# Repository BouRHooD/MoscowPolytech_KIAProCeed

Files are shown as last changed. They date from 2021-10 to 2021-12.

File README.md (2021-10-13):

<h1 align="center">Self-driving KIA ProCeed</h1>

---

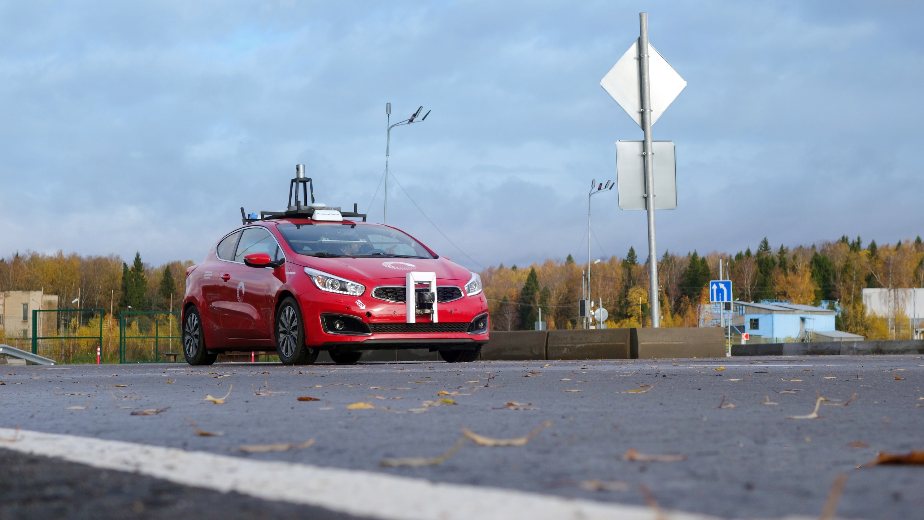
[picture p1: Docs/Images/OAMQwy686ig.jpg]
Иллюстрация к проекту


<p align="center">


  

  

  
</p>

RU: Беспилотное транспортное средство (БПТС) KIA ProCeed. Разрабатывается с использование микроконтроллеров Arduino, GNSS приёмник, Velodyne 3-D Lidar. Воздействие на органы управления автомобиля происходит посредством механических и электронных влияний, которые имитируют действия человека. Воздействие на руль происходит посредством DC мотора и потенциометра, который считывает текущее положение руля. Воздействие на педали сцепления и тормоза с помощью сервомоторов. Воздействие на педаль газа происходит с помощью ЦАП. 

Оборудование KIA ProCeed:
* **Лидар**, который нужен для определения положения автомобиля в пространстве и распознавания типов препятствий.
* **Приемник RTK GNSS**, обеспечивающий сантиметровую точность позиционирования автомобиля по спутникам GPS+ГЛОНАСС и поправкам наземных станций.

---

<h1 align="left"> Документация </h1>

[Инcтрукция по запуску автомобиля](https://github.com/BouRHooD/MoscowPolytech_KIAProCeed/raw/main/Docs/Connect_/Manual_po_ispolzovaniyu_KIA_ProCeed.pdf)

<h1 align="left"> Контакты </h1>
С нами можно связаться по почте bourhood@gmail.com

А еще у нас есть [Instagram](https://www.instagram.com/self.driving.mpu/?r=nametag)

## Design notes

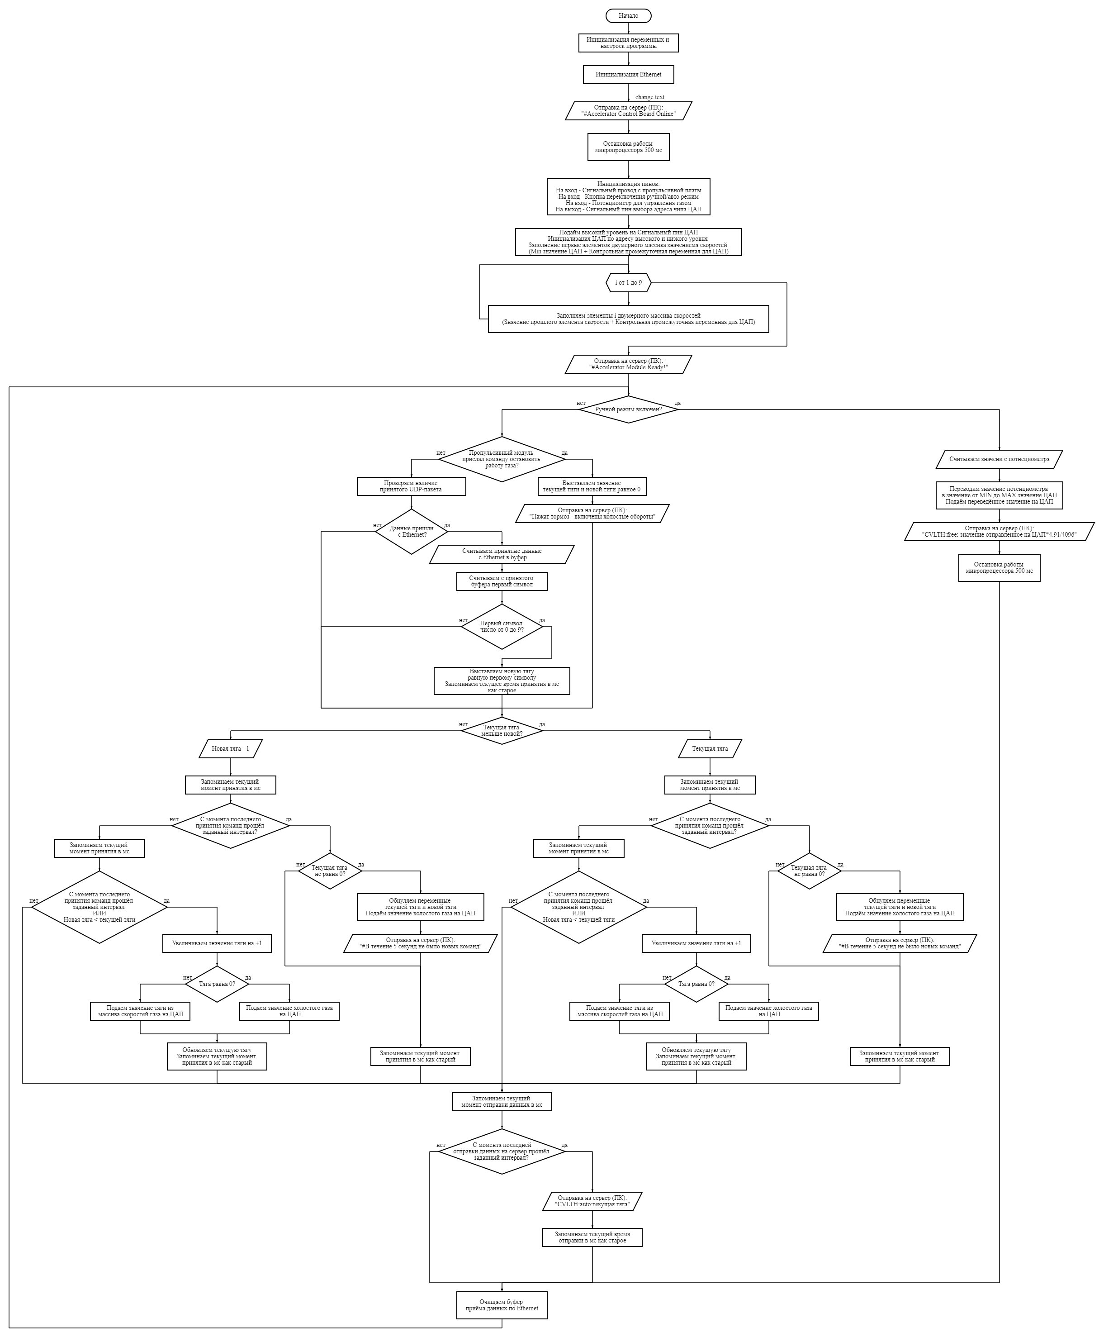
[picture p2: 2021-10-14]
Docs/Schemes/визуализация алгоритма управления газом Pro Ceed.png

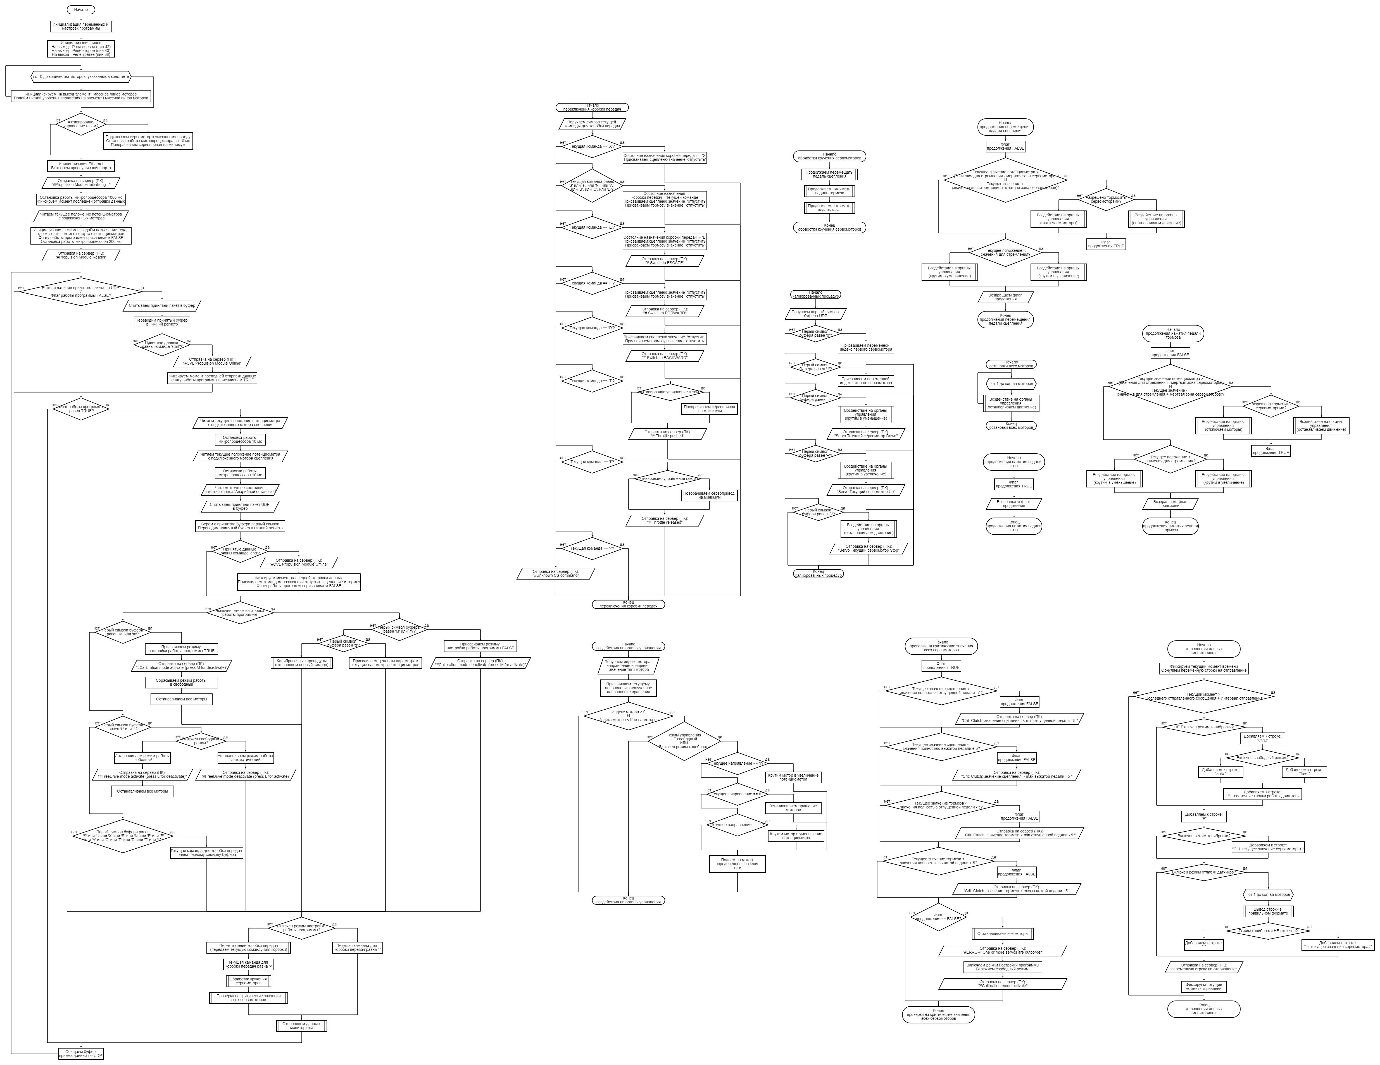
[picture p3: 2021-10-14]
Docs/Schemes/визуализация алгоритма пропульсивного модуля Pro Ceed.png

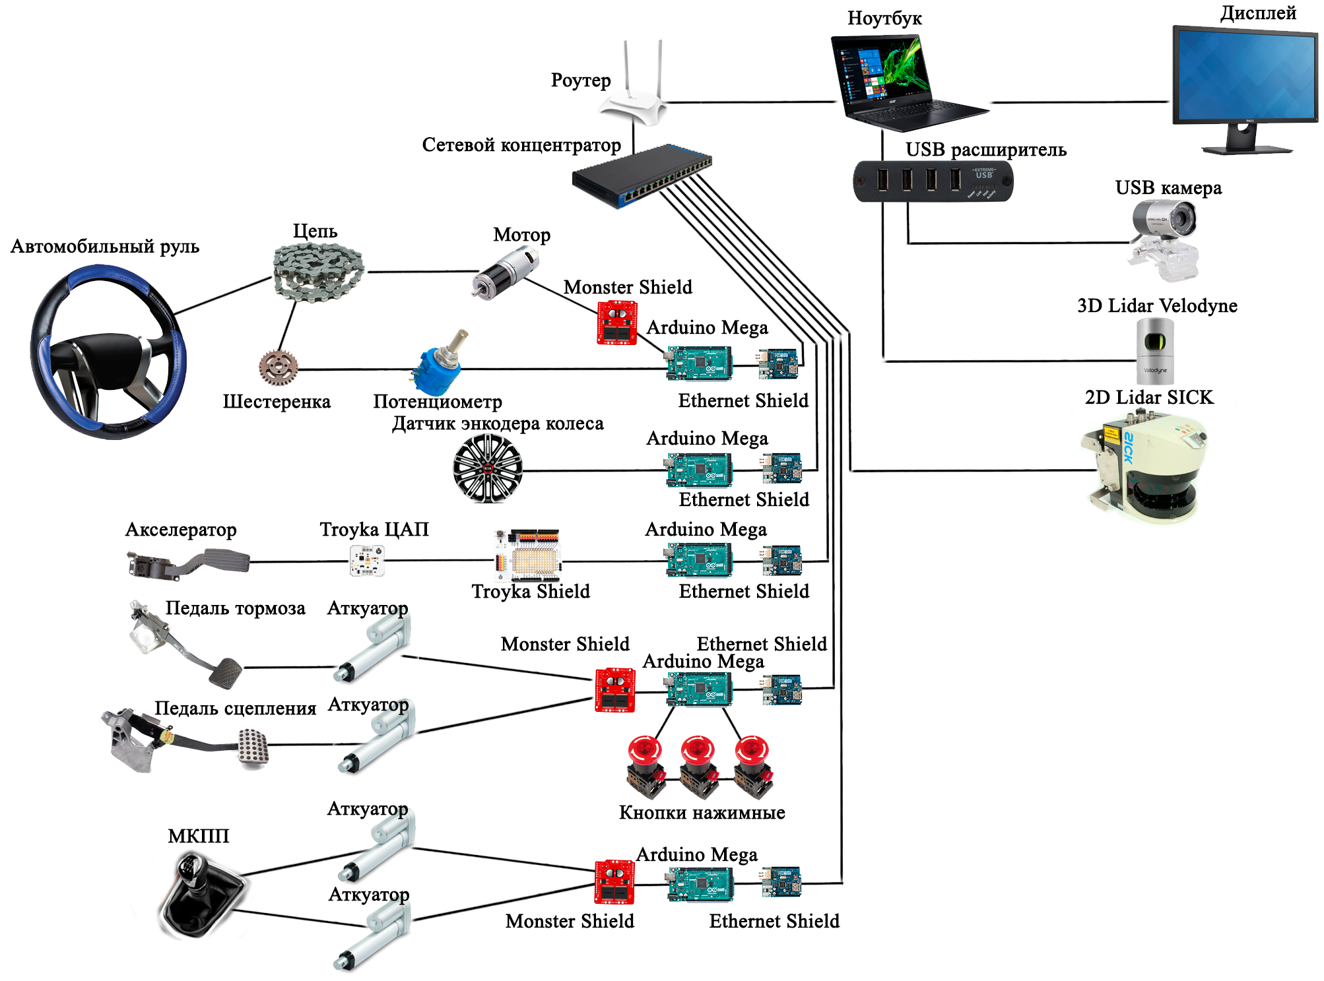
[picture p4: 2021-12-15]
Docs/Connect_/TopologyProject/Для топологии проекта KIA ProCeed.png

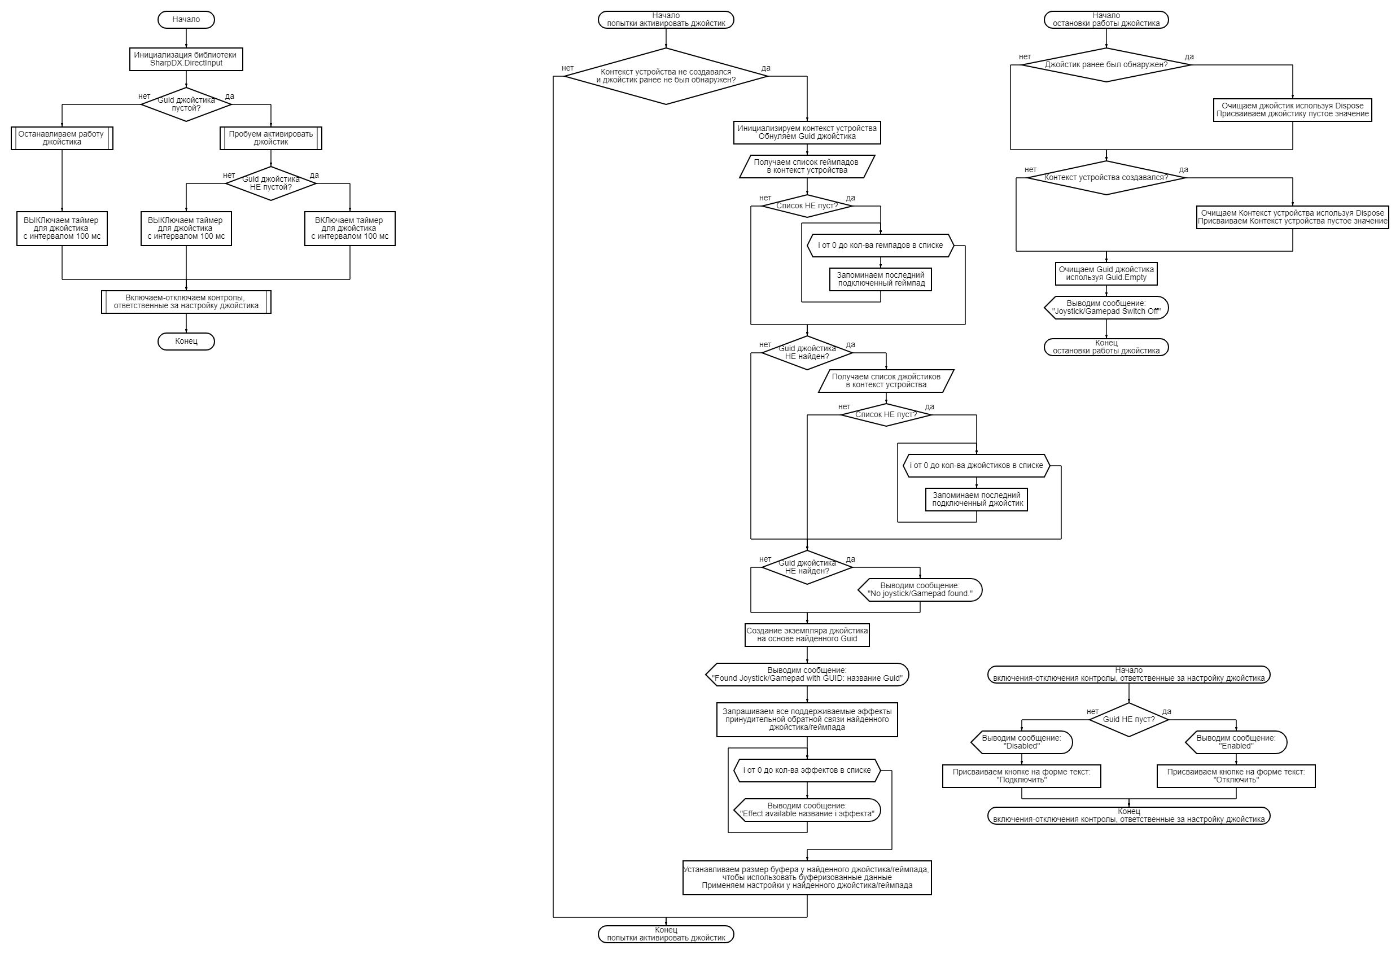
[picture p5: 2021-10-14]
Docs/Schemes/визуализация алгоритма управления джойстиком машины.png

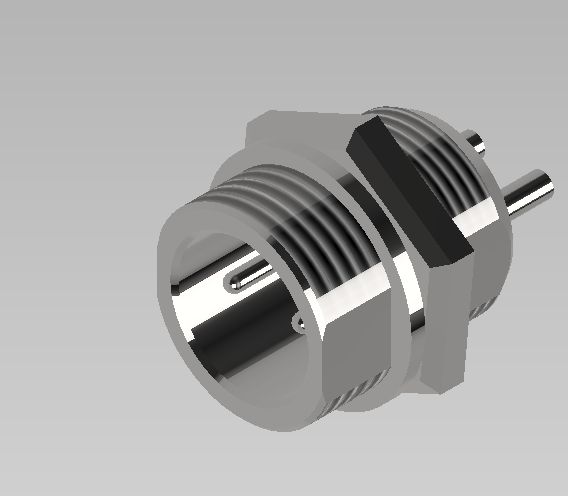
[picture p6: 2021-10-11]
Modeling/Blanks_Model/Руль (модуль)/3-pin/pic.jpg

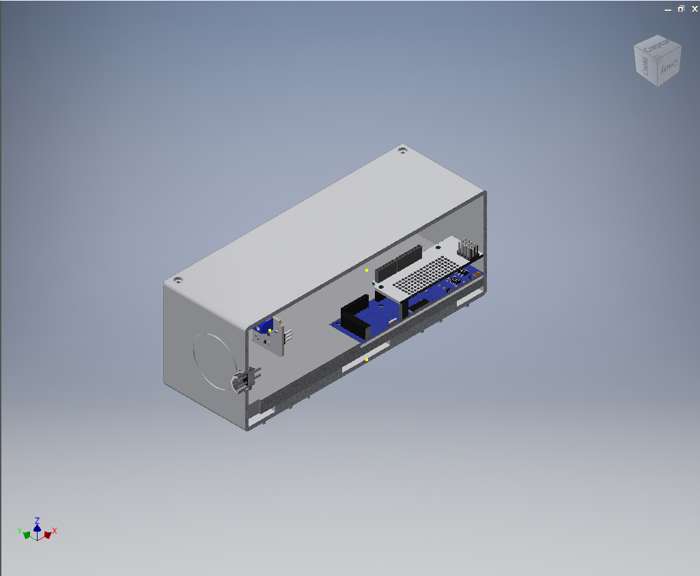
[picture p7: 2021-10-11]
Modeling/Blanks_Model/Газ (модуль)/Screenshot_4.png

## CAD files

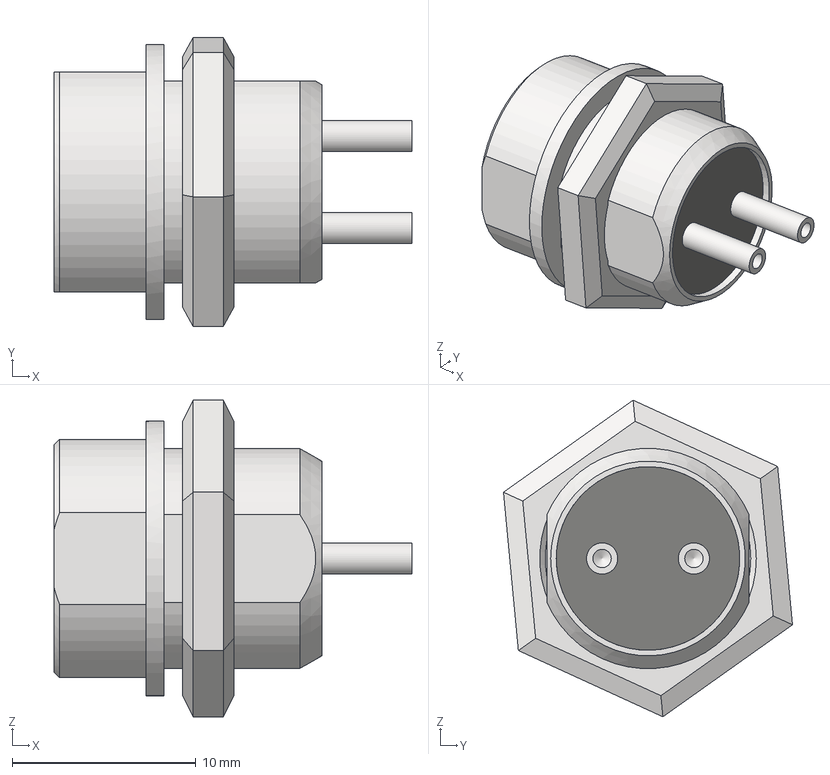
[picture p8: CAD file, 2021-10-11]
Modeling/Blanks_Model/Газ (модуль)/3-pin/3-pin.stp
19.5 x 15.7 x 17.2 mm
корпус разъема
каркас
kls_pin x 2
гайка

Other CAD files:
Modeling/Blanks_Model/New Дистанционная связь (модуль)/Arduino UNO.ipt
Modeling/Blanks_Model/New Дистанционная связь (модуль)/Arduino UNO/Arduino_Uno.ipt
Modeling/Blanks_Model/New Дистанционная связь (модуль)/NextionDisplay.ipt
Modeling/Blanks_Model/New Дистанционная связь (модуль)/OldVersions/A_Arduino_Uno_Wifi_Shield.0005.iam
Modeling/Blanks_Model/New Дистанционная связь (модуль)/OldVersions/Arduino_Wifi_Shield.0010.ipt
Modeling/Blanks_Model/New Дистанционная связь (модуль)/OldVersions/Monster_motor_Shield.0019.ipt
Modeling/Blanks_Model/New Дистанционная связь (модуль)/OldVersions/NextionDisplay.0002.ipt
Modeling/Blanks_Model/New Дистанционная связь (модуль)/OldVersions/Relay.0013.ipt
Modeling/Blanks_Model/New Дистанционная связь (модуль)/OldVersions/Аккумулятор.0001.ipt
Modeling/Blanks_Model/New Дистанционная связь (модуль)/OldVersions/Джойстик.0003.ipt
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

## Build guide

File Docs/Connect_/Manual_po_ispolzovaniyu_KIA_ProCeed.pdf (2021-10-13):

## Мануал по использованию KIA ProCeed

## Версия продукта 0.3

## Содержание

### 1. Проверка исправности ProCeedперед и после эксплуатации - Проверить целостность проводки

## Визуально оценить все ли в порядке – провода надежно подключены ко

всем элементам в обоих багажниках (первый в задней части машины, второй на крыше машины).

### - Проверить заряд аккумуляторов (под капотом и в багажнике)

## Если аккумуляторы подключены к машине, то включаем прерыватель масс, а затем смотрим на вольметры на основной панели и на месте держателя очков (?)

## Если аккумуляторы не подключены к машине, то можем проверить их заряд с помощью мультиметра

### - Убедиться, что все элементы надежно закреплены на машине

## Проверить крепления в обоих багажниках, элементы должны быть неподвижны. Также убедиться, что багажник прикручен саморезами к машине

### - Проверить уровень топлива

## Посмотреть на приборной панели уровень топлива

### - Проверить работоспособность всех Kill-Switch’ей

## Завести двигатель машины, а затем нажать на Kill-Switch, если машина заглохла, то кнопка работает (проделать операцию с каждой такой кнопкой)

## В случае обнаружения проблемобратиться к старшему по команде

### 2. Инструкция по эксплуатации ProCeed

### 1. Включение

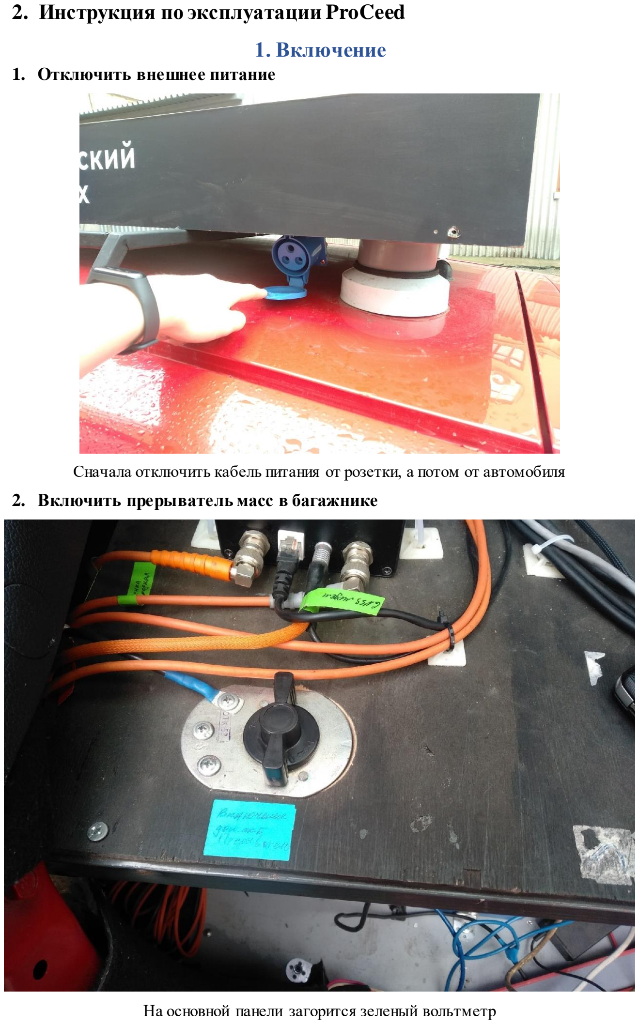
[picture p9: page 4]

### 1. Отключить внешнее питание

Сначала отключить кабель питания от розетки, а потом от автомобиля

### 2. Включить прерыватель масс в багажнике

На основной панели загорится зеленый вольтметр

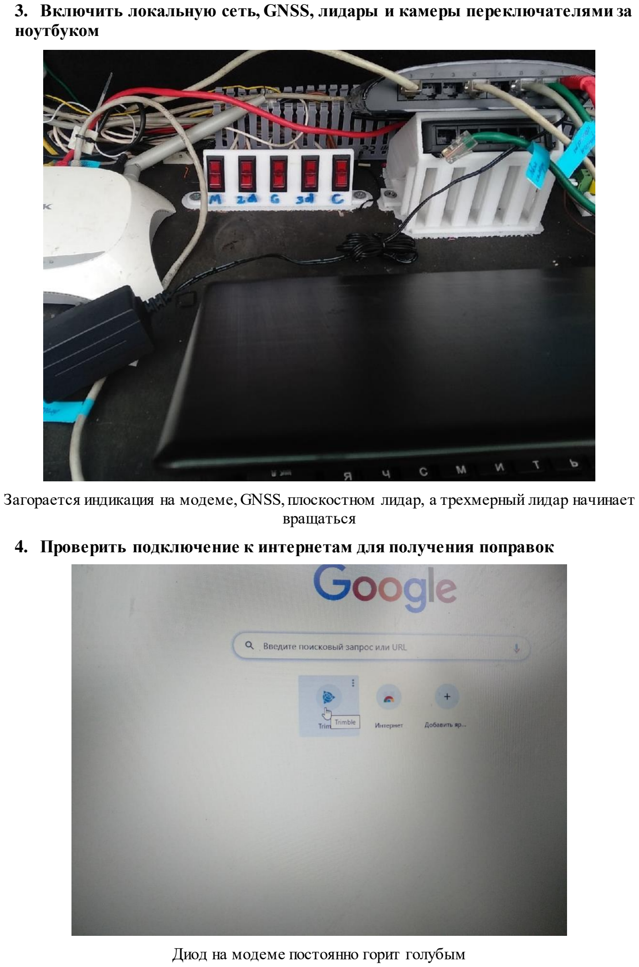
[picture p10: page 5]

### 3. Включить локальную сеть, GNSS, лидары и камеры переключателями за

ноутбуком

Загорается индикация на модеме, GNSS, плоскостном лидар, а трехмерный лидар начинает вращаться

### 4. Проверить подключение к интернетам для получения поправок

Диод на модеме постоянно горит голубым

### 5. На рабочем столе запустить файл Robocross2018

### 6. В окне “Подключение оборудования” подключить платы управления в

соответствии с портами подключения

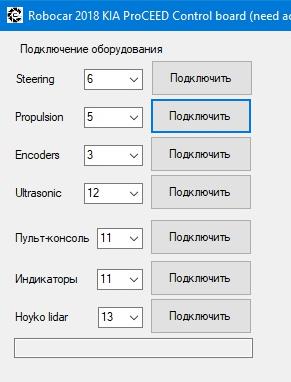
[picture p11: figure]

Steering 6, Propulsion 5, Encoders 3, Пульт консоль 11, Индикаторы 11 и т.д. В соответвующих окнах появятся данные от датчиков обратной связи

### 7. В окне настроек RTK подключить систему GNSS

В соответвующих окнах появятся координаты и курс из протокола NMEA. При отсутствии курса, окно курса имеет красный цвет. Состояние приемника проверяется по адресу 192.168.0.3

### 8. В окне “Запуск миссии”, выбрать нужную миссию. Нажать на кнопку

“Загрузить миссию”

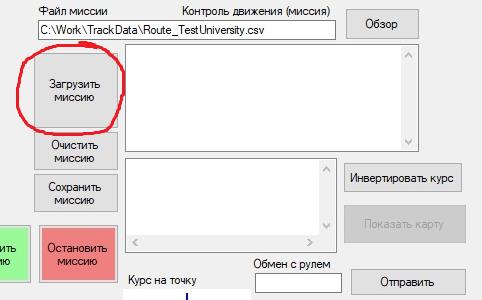
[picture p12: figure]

В консоли появятся координаты и курс. Если система GNSS работает корректно, то на карте появятся точки

### 9. Запустить двигатель

Прожать педаль сцепления и одновременно повернуть вставленный ключ зажигания по часовой стрелке

### 10. Включить основное питание на передней панели

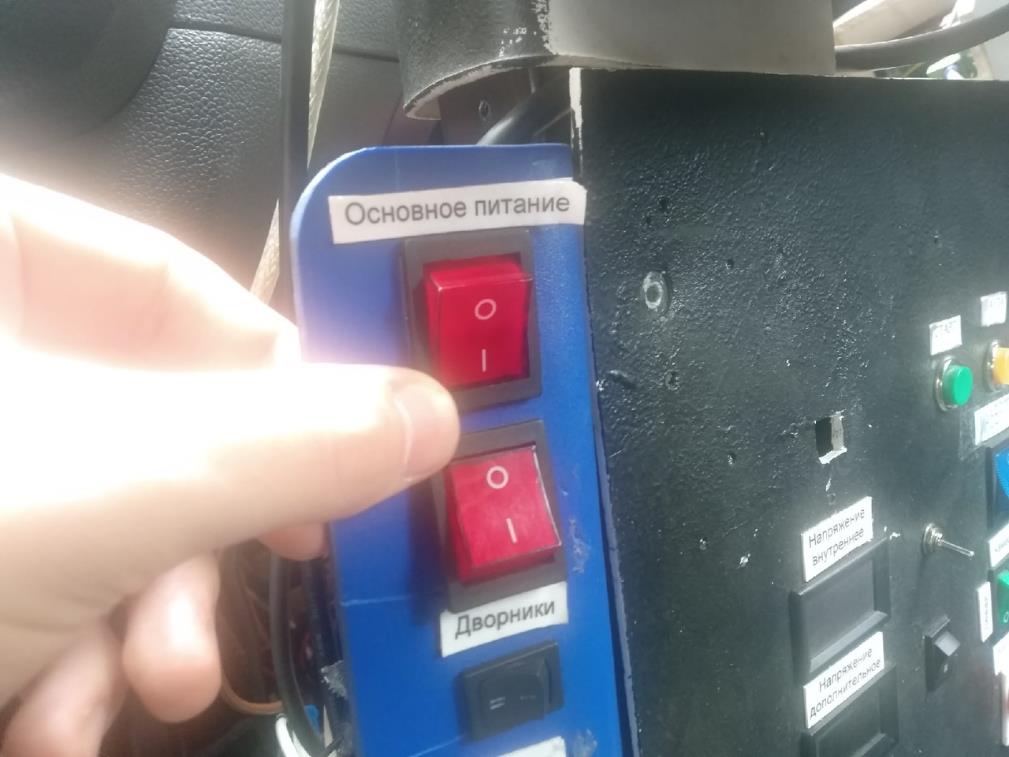
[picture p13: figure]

Загорится красный вольтметр, а на платах загорятся красные диоды

### 11. Перевести пропульсивный модуль в свободный режим, отправив команду

M

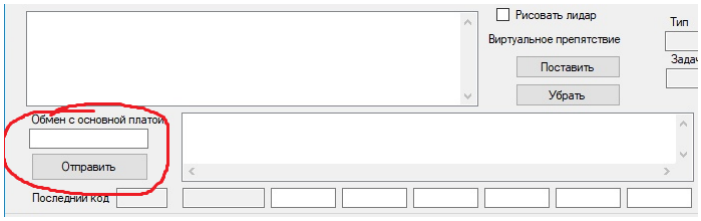
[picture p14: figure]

### 12. Перевести пропульсивный модуль в автоматический режим, отправив

команду L

### 13. В консоль пропульсивного модуля отправить букву E

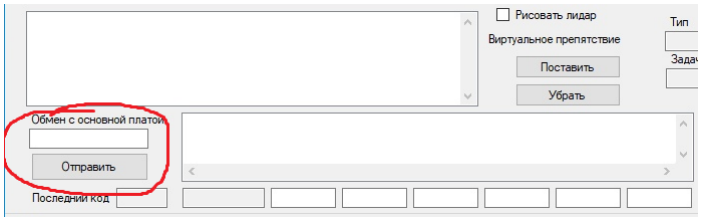
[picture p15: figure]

Актуаторы задвинутся в начальное положение

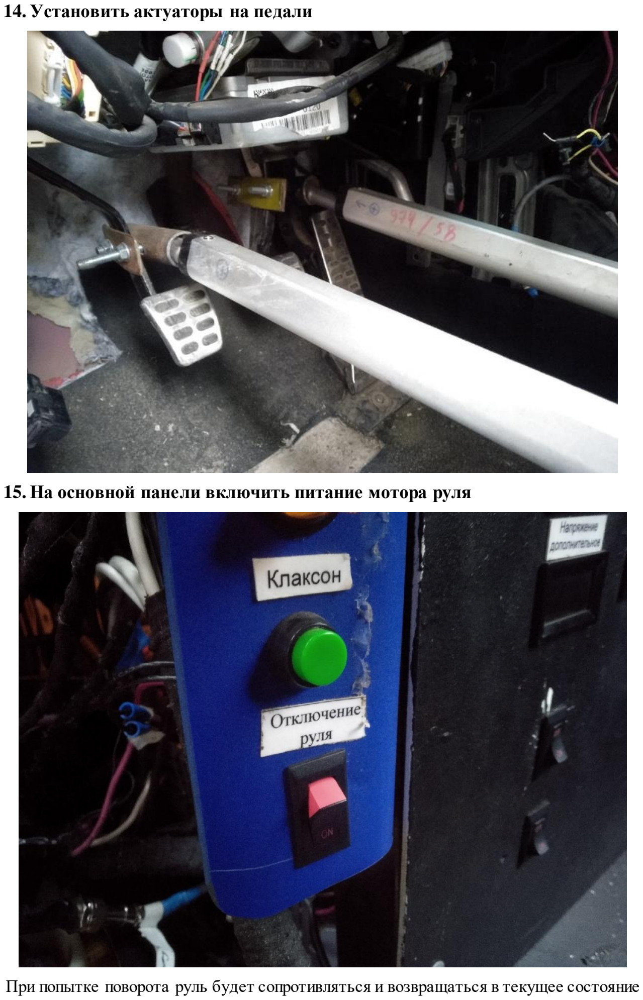
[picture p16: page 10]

### 14. Установить актуаторы на педали

### 15. На основной панели включить питание мотора руля

При попытке поворота руль будет сопротивляться и возвращаться в текущее состояние

### 16. Перевести модуль управления руля в автоматический режим, отправив

команду A

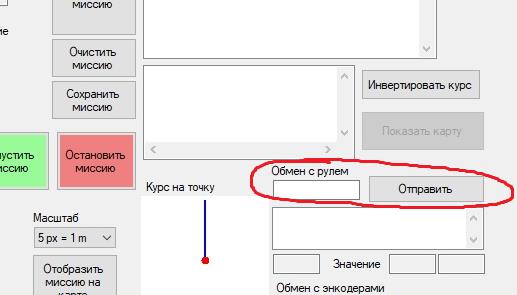
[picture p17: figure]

### 17. Отправить в консоль пропульсивного модуля команду B

Актуаторы тормоза и сцепления нажмут на педали

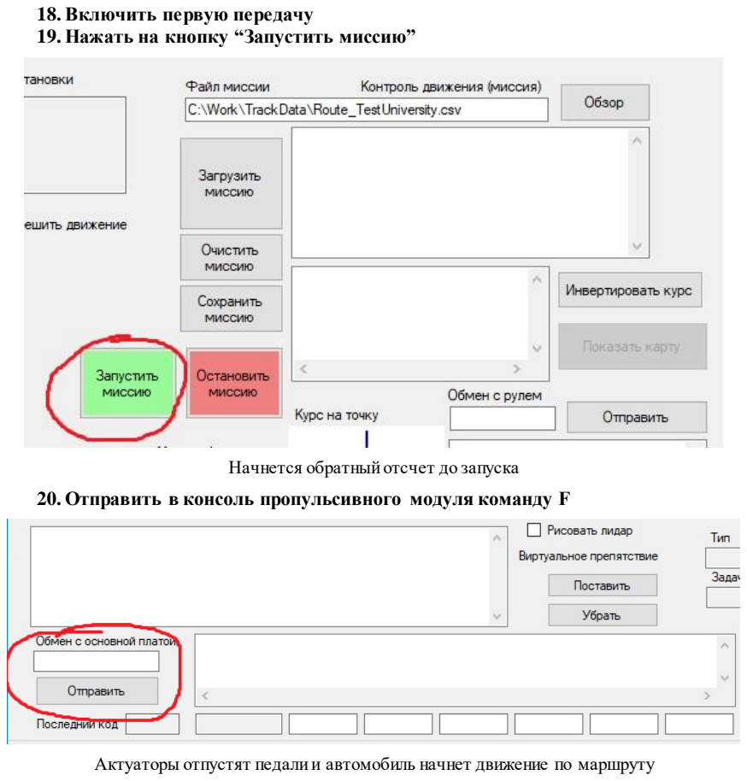
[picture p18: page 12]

### 18. Включить первую передачу 19. Нажать на кнопку “Запустить миссию”

Начнется обратный отсчет до запуска

### 20. Отправить в консоль пропульсивного модуля команду F

Актуаторы отпустят педали и автомобиль начнет движение по маршруту

### 2.Выключение

### 1. Заглушить двигатель

В положении покоя машины повернуть ключ против часовой стрелки

### 2. Поставить автомобиль на ручник 3. В консоль пропульсивного модуля отправить команду E

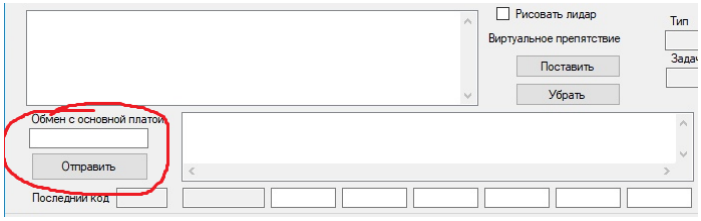
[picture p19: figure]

Актуаторы задвинутся в начальное положение

### 4. Снять актуаторы с педалей 5. На основной панели выключить питание мотора руля

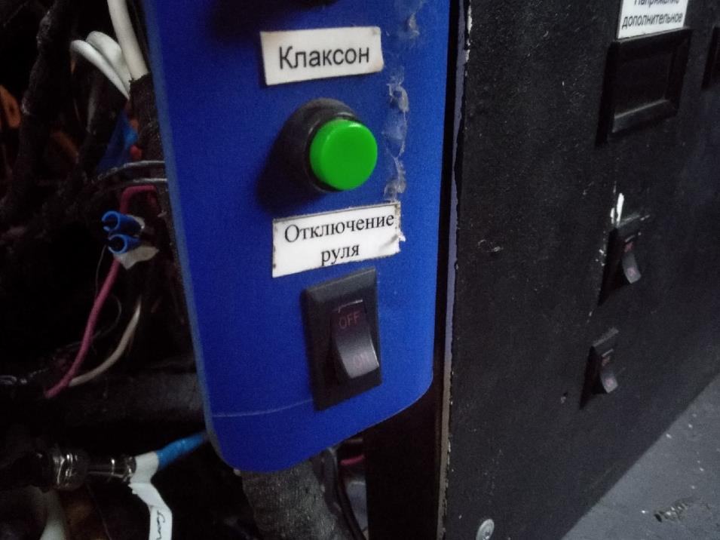
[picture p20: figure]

При попытке поворота руль не будет сопротивляться и возвращаться в текущее состояние

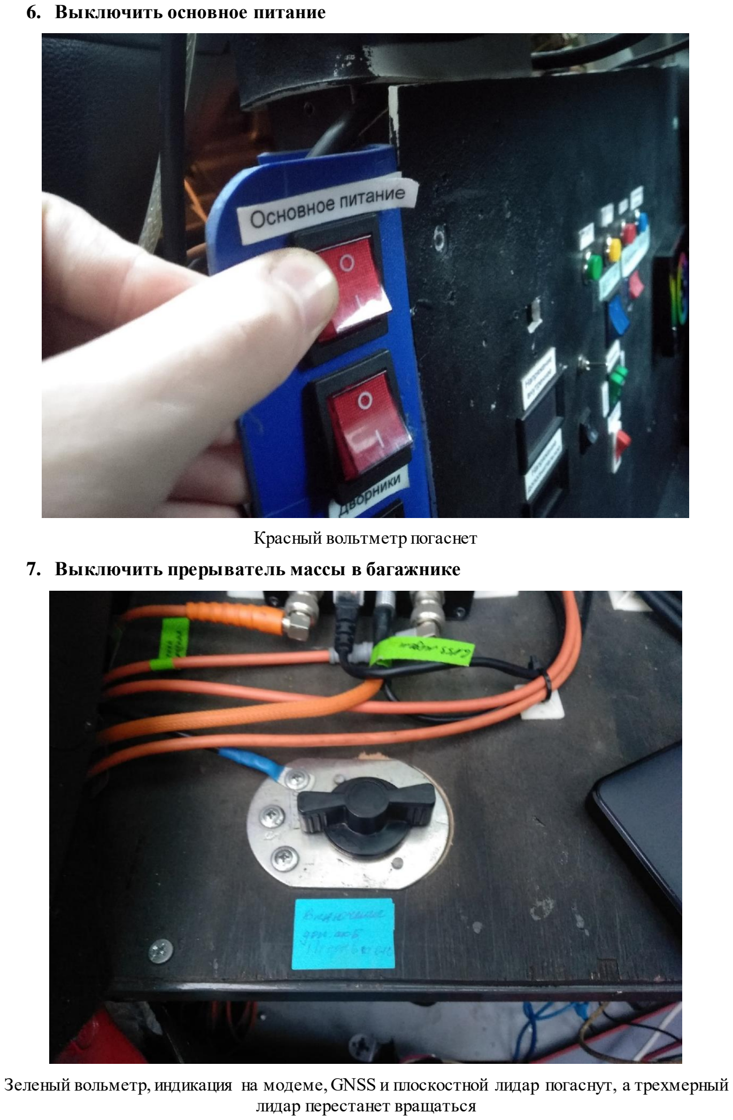
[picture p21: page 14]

### 6. Выключить основное питание

Красный вольтметр погаснет

### 7. Выключить прерыватель массы в багажнике

Зеленый вольметр, индикация на модеме, GNSS и плоскостной лидар погаснут, а трехмерный лидар перестанет вращаться

### 8. Подключить внешнее питание для зарядки

Сначала подключение к машине, а потом к розетке

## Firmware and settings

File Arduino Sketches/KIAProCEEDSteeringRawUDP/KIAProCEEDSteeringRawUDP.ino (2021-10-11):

/*
Система управления платой контроля рулевого колеса Робокара Мосполитеха (в конфигурации "Зимний город 2019") для KIA ProCeed

Версия 23.10.2020 by Leonov Vladislav 181-311

Введена коррекция скорости вращения (снижение мощности при приближении к зоне точного руления)

Система управления с 1 x Arduino Uno, 1 x Monster Shield, 1 x Troyka Shield, 1 х Тумблер, 1 x Ethernet Shield

"Механическая" калибровка: *  
  - мотор руля: при прямом включении должен крутиться вправо
  - потенциометр руля:
     - возрастает при вращении руля вправо
     - 500 в средней позиции (прямо)

!!!!!  ВАЖНО  !!!!
Ведется непрерывный контроль тока через рулевой мотор. В случае превышения номинального значения 
мотор отключается с индикацией авария в 1 (авария)
!!!!!  ВАЖНО  !!!!

К плате подключен тумблер отключения автоматического режима руления.

При включении платы даже в автоматическом режиме (тумблер) вращение не производится до поступления по Serial
любой корректной команды активации вращения (число от 100 до 999).

Конфигурация системы:
Arduino Uno
Monster Motor Shield
Troyka Shield
Ethernet Shield

Управляющие и мониторинговые пины:
Руль (Steering)

Управление через Ethernet Shield (штатный режим):

{100 - 999}  руль   100 - влево до упора, 500 - середина, 999 - вправо до упора
Окончание ввода # или \n. Можно подождать 0,5 секунды и строка обработается сама.

S         остановка вращения руля
F         свободный режим
A         включение автоматического режима (после F)

Тумблер не связан с командами программного управления, а отключает "передачу команд на мотор".
*/

// Настройки внешних устройств 
#define ledPin 13                                           // Мигаем светодиодом при исправной работе
 
//  ------------------------------ РУЛЬ ------------------------------
/*
int inApin[2] = {7, 4};  // INA: Clockwise input
int inBpin[2] = {8, 9}; // INB: Counter-clockwise input
int pwmpin[2] = {5, 6}; // PWM input
int cspin[2] = {2, 3}; // CS: Current sense ANALOG input
int enpin[2] = {0, 1}; // EN: Status of switches output (Analog pin)
 */
#define SteeringPinA    4
#define SteeringPinB    9
#define SteeringPWMPin  6
#define SteeringPotentiometer A5                            // Потенциометр руля
#define SteeringCSPin A2
#define SteeringENPin A0
#define SteeringMax    710                                  // Вправо (ПРЕДЕЛЬНОЕ! значение для ограничителя)
#define SteeringCenter  500                                 // Середина (КАЛИБРОВОЧНОЕ! значение середины)
#define SteeringMin     290                                 // Влево   (ПРЕДЕЛЬНОЕ! значение для ограничителя)
#define SteeringStPWMValueFast 200                          // Стандартное значение
#define SteeringStPWMValueSlow 100                          // Сниженная тяга
#define SteeringAccurateZone 15                             // Зона около destvalue где выполняется снижение мощности мотора
#define SteeringCriticalLoad 1000                           // Предельное значение нагрузки. Измеряется ток (Current) на SteeringCSPin
#define SteetingCriticalLoadTimeOut 1000                    // Время, при превышении которого при повышенной нагрузке тяга сбрасывается

int SteeringStPWMValue = SteeringStPWMValueFast;

#define servofreezone 5  // мертвая область серв

// Переменные контроля режимов (управляются тумблерами) -------------- 
bool isFreeMode = true;                               
// Свободный режим - управление по значению энкодера (потенциометра) не выполняется
bool isUseServoBrake = true;                                // Разрешение торможения серв    

// датчики
int posvalue = 500;                                         // Позиции текущие (с потенциометров)
int destvalue = 500;                                        // Позиции назначения (ожидаемые)
int marginvalue = 2;                                        // Зазоры контроля достижения нужной позиции

// Ввод-вывод
char SteeringCMD = '-';                                     // Буфер символа для команды для руля
String SteeringCMDLine = "";                                // Буфер команды для руления

bool SCtrl = false;                                         // Контроль руления

// Параметры ожидания прихода разделителя данных
unsigned long LastInputMoment = 0;                          // Время прихода последнего символа управляющей команды
unsigned long CurrentInputMoment = 0;                       // Расчет времени прихода данных
unsigned long InputTimeOutInterval = 250;                   // Оидания управшяющих данных в миллисекундах

// Параметры отправки мониторинговых данных по Ethernet --------------
unsigned long LastSendingMoment = 0;                        // Время предыдущей отправки
unsigned long CurrentMoment = 0;                            // Текущей момент отправки
unsigned long SendingInterval = 500;                        // Частота (интервал) оправки данных в миллисекундах

// Рабочие переменные разного назначения -----------------------------
char cmd;
char val;
int intvalue = 0;

#include <Ethernet.h>
#include <EthernetUdp.h>
#include <SPI.h>

//#-------- UDP configuration-------#
// Ниже укажите MAC-адрес и IP-адрес вашего контроллера .
// IP-адрес будет зависеть от настроек вашей локальной сети:
// При присваивании IP адрессов следует посмотреть доступные в маршрутизаторе
byte mac[] = {   0x90, 0xA2, 0xDA, 0x10, 0x13, 0xBB };
IPAddress boardIP (192, 168, 0, 200);                       // IP платы
IPAddress hostIP (192, 168, 0, 100);                        // IP server
unsigned int boardPort = 88;                                // Порт платы
unsigned int hostPort = 90;                                 // Порт сервера

EthernetUDP UDP;                                            // Создание экземпляра класса EthernetUDP для отправки и получения UDP-пакетов
char packetBuffer[UDP_TX_PACKET_MAX_SIZE];                  // Храним полученный пакет (приемный буфер Udp-пакета)
bool isStarted = false;                                     // Флаг работы программы

void setup() 
{
    // Настраиваем выходы управляющих линий
    pinMode(SteeringPinA, OUTPUT);
    pinMode(SteeringPinB, OUTPUT);
    pinMode(SteeringPWMPin, OUTPUT);

    digitalWrite(SteeringPinA, LOW);
    digitalWrite(SteeringPinB, LOW);
    analogWrite(SteeringPWMPin, 0);
   
    // инициализация режимов // задаём назначение туда, где мы есть в момент старта
    destvalue = 500; //analogRead(SteeringPotentiometer);
    
    //SteeringTo('5');  // ставим руль в середину  <---------- не делаем так при штатной работе (должно быть закомменчено)
    Ethernet.begin(mac, boardIP);                           // Инициализируем плату контроллера
    UDP.begin(boardPort);                                   // Включаем прослушивание порта
    UDP.beginPacket(hostIP, hostPort);                     
    UDP.write("#CVL Steering Control Board Ready!");  
    UDP.endPacket();
    LastSendingMoment = millis();                           // Фиксируем момент последней отправки данных
    delay(500);
}

void loop() 
{   
  //#1 Начало работы кода при включении платы один раз 
  if(UDP.parsePacket() > 0 && !isStarted){
    UDP.read(packetBuffer, UDP_TX_PACKET_MAX_SIZE);         // Cчитываем принятый пакет в буфер packetBufffer
    String comand = packetBuffer;                       
    comand.toLowerCase();
    if(comand == "start"){
      // Отсылаем пакет данных серверу:  
      UDP.beginPacket(hostIP, hostPort);                     
      UDP.write("#CVL Steering Control Board Online");  
      UDP.endPacket();
      LastSendingMoment = millis();                         // Фиксируем момент последней отправки данных
      isStarted = true;
    }
  }
  //#1 Конец работы кода при включении платы один раз 
  
  if(isStarted){ 
    // читаем все потенциометры
    //posvalue = analogRead(SteeringPotentiometer);
    posvalue = 555;

    // время начала цикла обработки
    CurrentInputMoment = millis();
    
    // обработка ввода-вывода по Ethernet  
    UDP.read(packetBuffer, UDP_TX_PACKET_MAX_SIZE);         // считываем принятый пакет в буфер packetBufffer

    //#2 Начало завершения работы кода 
    String comand = packetBuffer;                       
    comand.toLowerCase();
    if(comand == "end"){
    LastInputMoment = CurrentInputMoment;                   // Запоминаем текущий момент обработки
    comand = "";
    // Отсылаем пакет данных серверу:  
    UDP.beginPacket(hostIP, hostPort);                        
    UDP.write("#CVL Steering Control Board Offline");  
    UDP.endPacket();
    LastSendingMoment = millis();                           // Фиксируем момент последней отправки данных
    isStarted = false;
    }
    //#2 Конец завершения работы кода  
  
    char SteeringCMD = packetBuffer[0];                     // Считываем с принятого буфера первый символ
    
    switch (SteeringCMD)
    {
            case 'S': case 's':                             // остановка вращения     
                SendFeedback("#Stop motor");      
                StopMotorSafe();
                destvalue = posvalue;               
                SendFeedback("#Execute");               
                ProcessCMDBuffer();
                LastInputMoment = CurrentInputMoment;       // запоминаем текущий момент обработки
                SteeringCMD = '-';                          // Очищаем буфер символа для команды руля
                SteeringCMDLine = "";                       // Очищаем буфер команд для руления
                break;
            case 'F': case 'f':                             // включение свободного режима     
                SendFeedback("#Stop motor");                // Отправляем сообщение UDP
                StopMotorSafe();                            // Останавливаем мотор
                destvalue = posvalue;                       // Присваеваем значение стремления потенциометра текущее значение
                isFreeMode = true;                          // Переводим в режим свободного управленич
                SendFeedback("#Execute");                   // Отправялем сообщение UDP
                ProcessCMDBuffer();                         // 
                LastInputMoment = CurrentInputMoment;       // запоминаем текущий момент обработки
                SteeringCMD = '-';                          // Очищаем буфер символа для команды руля
                SteeringCMDLine = "";                       // Очищаем буфер команд для руления
                break;                    
            case 'A': case 'a':                             // включаем автоматический режим (из Safe Mode)
                isFreeMode = false;
                destvalue = posvalue;               
                SendFeedback("#Execute");               
                ProcessCMDBuffer();
                LastInputMoment = CurrentInputMoment;       // запоминаем текущий момент обработки
                SteeringCMD = '-';                          // Очищаем буфер символа для команды руля
                SteeringCMDLine = "";                       // Очищаем буфер команд для руления
                break;
            /*
             * case 'E': case 'e':                          // Завершение работы кода                                
            SendFeedback("CVL Steering Control Board Offline");               
            LastInputMoment = CurrentInputMoment;           // запоминаем текущий момент обработки
            isStarted = false;
            SteeringCMD = '-';                              // Очищаем буфер символа для команды руля
            SteeringCMDLine = "";                           // Очищаем буфер команд для руления
            break;
            */
            case '0': case '1': case '2': case '3': case '4': case '5': case '6': case '7': case '8': case '9':
                // рулим                   
                //SteeringCMDLine += SteeringCMD;           // Заполняем буфер команд для руления
                SteeringCMD = '-';                          // Очищаем буфер символа для команды руля
                SendFeedback("#Execute");               
                ProcessCMDBuffer();
                SteeringCMDLine = packetBuffer;
                LastInputMoment = CurrentInputMoment;       // Время прихода последнего символа управляющей команды
                break;  
        }  // switch 

    if (CurrentInputMoment > LastInputMoment + InputTimeOutInterval) // Если прошло много времени от старых данных, то обработаем что есть.
    {
        ProcessCMDBuffer();                                 
        SteeringCMDLine = "";                               // Очищаем буфер команд для руления
        LastInputMoment = CurrentInputMoment;               // Запоминаем текущий момент обработки
    }

    SteeringCMD = '-';                                      // Очищаем буфер символа для команды руля
    
    // автоматическое руление подразумевает коррекцию скорости вращения - выполняется внутри процедуры "продолжения руления"
    SteeringContinue();                                     // продолжаем крутить руль           
    // Проверка на критические значения сервомотора
    CheckServoCritical();                                   // <-- при ошибке сама остановит сервомотор        
    SendDataIfNeed();                                       // Отправка данных мониторинга, если необходимо
    memset(packetBuffer, 0, UDP_TX_PACKET_MAX_SIZE);        //Очищаем буфер приёма данных  
  }  // ---------------- isStarted ----------------
}  // ---------------- end of loop() ----------------

void SendFeedback(String str){
   int strLength = str.length();                            // Длина строки
   char response[strLength+1];                              // Объявляем массив char размером входной строки str
   str.toCharArray(response,sizeof(response));              // Переводим строку в массив char
   UDP.beginPacket(hostIP, hostPort);                       // Начало отправки данных (кому будем отправлять данные)
   UDP.write(response);                                     // Данные,которые отправляем
   UDP.endPacket();                                         // Конец отправки данных
   LastSendingMoment = millis();                            // Фиксируем момент последней отправки данных
}

void SendDataIfNeed()//-------------------------------------// Отправка данных мониторинга, если пришло время
{
    CurrentMoment = millis();           
    if (CurrentMoment > LastSendingMoment + SendingInterval)
    {
        // -- Отправляем текущие данные управления --        
        //  CVLST:500:650#   ключ:режим:текущее положение:требуемое положение
        String com ="CVLST:";
        if (isFreeMode) 
        {
            com += "free:";
        }
        else
        {
           com += "auto:";
        }
        
        // -- Завершение отправки контрольных данных --
        com += String(posvalue);
        com += ":" + String(destvalue)+"#";
        SendFeedback(com);                                  // ОТПРАВЛЯЕМ пакет данных по UDP
        LastSendingMoment = millis();                       // Сохраняем текущее время как "старое"
    }
}  // ------------------------------------------------------//end of SendDataIfNeed()

void ProcessCMDBuffer()//-----------------------------------// обработка буфера входных данных (преобразуем в число и если входит в диапазон - исполняем)
{
    int m = 0;
    m = SteeringCMDLine.toInt();
    if ((m >= SteeringMin) && (m < SteeringMax))
    {
        destvalue = m;
    }
    SteeringCMDLine = "";                                   // Очищаем буфер
}  // ------------------------------------------------------//end of ProcessCMDBuffer() 

void SerialPrintFormattedInt(int n)//-----------------------// Печатаем форматированное число всегда в 4 символа 
{
    if (n < 10)
    {
        SendFeedback("   ");
    }
    else if (n < 100) 
    {
        SendFeedback("  ");
    }
    else if (n<1000)
    {
        SendFeedback(" ");
    }
    
    SendFeedback(String(n));
} // -------------------------------------------------------//end of SerialPrintFormattedInt() 

bool CheckSteeringPosition()//------------------------------// если руль в диапазоне целевой позиции, то значение true
{
    bool ctrl = false;
    ctrl = ((posvalue >= destvalue - marginvalue) && (posvalue <= destvalue + marginvalue));
    return ctrl;
}  // ------------------------------------------------------//end of CheckSteeringPosition()

// Проверка критических значений потенциометров серв ===========================================

void CheckServoCritical()
{  
    if (posvalue < SteeringMin - 5)                         // руль "слишком влево"
    { 
       String com = "CVLST:Crit:";
       com += String(posvalue) + ":";
       com += String(destvalue);
       com += "#Steering critical: " + String(posvalue);
       com += " < " + String(SteeringMin) + "(min)";
       SendFeedback(com);                                   // ОТПРАВЛЯЕМ пакет данных по UDP        
       StopMotorSafe();                                     // торможение или отключение сервомотора
       String Error = "#ERROR! Steering servo is outborder!  Board switch to Safe Mode";
       SendFeedback(Error);                                 // ОТПРАВЛЯЕМ пакет данных по UDP
       isFreeMode = true;         
    }
    else if (posvalue > SteeringMax + 5)                    // руль "слишком вправо"
    {
      String com = "CVLST:Crit:";
      com += String(posvalue) + ":";
      com += String(destvalue);
      com += "#Steering critical: " + String(posvalue);
      com += " > " + String(SteeringMax) + "(max)";
      SendFeedback(com);                                    // ОТПРАВЛЯЕМ пакет данных по UDP
      StopMotorSafe();                                      // Торможение или отключение сервомотора
      String Error = "#ERROR! Steering servo is outborder!  Board switch to Safe Mode";
      SendFeedback(Error);                                  // ОТПРАВЛЯЕМ пакет данных по UDP
      isFreeMode = true; 
    }
}

// Функции воздействия на органы управления ====================================================
void SteeringDCMotorControl(int motorDirect, int motorPower)// Управление мотором постоянного тока (для руля)
{    //   motorDirect == 0  - оба канала "вниз", -1  - мотор "в уменьшение потенциометра", 1 - мотор "в увеличение потенциометра"  !!!! ЭТО ОЧЕНЬ ВАЖНО ДЛЯ ЛОГИКИ КОНТРОЛЯ СЕРВ
     //   
    int currentDirect = motorDirect;
    // -- непосредственно крутим моторы -----
    {
        // задаем направление в зависимости от кода
        if (currentDirect == 1)
        {
            digitalWrite(SteeringPinA, LOW);
            digitalWrite(SteeringPinB, HIGH);
        }
        else if (currentDirect == 0)
        {
            digitalWrite(SteeringPinA, LOW);
            digitalWrite(SteeringPinB, LOW);
        }
        else if (currentDirect == -1)
        {
            digitalWrite(SteeringPinA, HIGH);
            digitalWrite(SteeringPinB, LOW);
        }
        // задаем тягу
        analogWrite(SteeringPWMPin, motorPower);            // тяга мотора (значение PWM)     
        delay(100);
    }      
}  // -- end of DCMotorControl() ---

// ========================== Руль ===============================

void StopMotorSafe()                                        // отключение или торможение мотора в зависимости от разрешения включать моторный тормоз
{
    if (isUseServoBrake)
    {
        StopMotor();
    }
    else
    {
        SwitchOffMotor();
    }
} // --- end of StopMotorSafe() ----

void StopMotor() //  торможение мотора
{
    SteeringDCMotorControl(0, SteeringStPWMValue);          // томозим мотор      
}

void SwitchOffMotor()  // отключение сервомотора
{
    SteeringDCMotorControl(0, 0);                           // отключаем мотор      
} 

void SteeringStopMotor()  // стопорим мотор руля и через треть секунды отпускаем
{
    SteeringDCMotorControl(0, SteeringStPWMValue);          // томозим мотор
    delay(300);                                             // немного ждем 
    posvalue = analogRead(SteeringPotentiometer);
    destvalue = posvalue;                                   // записываем текущее положение как целевое
    SteeringDCMotorControl(0, 0);                           // отключам мотор
    delay(100);
}

bool SteeringMoveToState(int NeedState) // true - если позиция достигнута 
{
    bool ctrl = false; 
    if (destvalue == NeedState)
    {
        ctrl = SteeringContinue();
    }
    return ctrl;
}  // --- end of SteeringMoveToState() -----------

bool SteeringContinue() // продолжаем вращать руль, true - если позиция достигнута
{     
    bool ctrl = false;
    int currentvalue = posvalue;

    if ((currentvalue >= destvalue - SteeringAccurateZone)&&(currentvalue <= destvalue + SteeringAccurateZone)) // настройка скорости вращения
    {
        SteeringStPWMValue = SteeringStPWMValueSlow;        // медленно вблизи
    }
    else
    {
        SteeringStPWMValue = SteeringStPWMValueFast;        // быстро вдали
    }

    if (!isFreeMode)  // если небезопасный режим, то можно крутить руль
    {
    // теперь выбираем направление вращения
        if (CheckSteeringPosition()) // руль в требуемом положении, стопорим
        {
            if (isUseServoBrake)  // используем тормоз сервопривода
            {          
                SteeringDCMotorControl(0, SteeringStPWMValue);
            }
            else // просто отключаем моторы
            {
                SteeringDCMotorControl(0, 0);
            }
            ctrl = true;  // <-- можно переходить к следующей команде
        } 
        else if (currentvalue < destvalue) // значение меньше - нужно крутить в увеличение
        {
            SteeringDCMotorControl(1, SteeringStPWMValue);
        }
        else // currentvalue > destvalue) // значение больше - нужно крутить в уменьшение
        {
            SteeringDCMotorControl(-1, SteeringStPWMValue);
        }
    }
    return ctrl;    
} // --- end of SteeringContinue() ---------

 

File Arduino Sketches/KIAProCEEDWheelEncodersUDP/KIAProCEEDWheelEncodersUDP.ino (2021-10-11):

/*
Мониторинг данных робокара 

Прямое считывание датчиков с Arduino Mega системы управления.

28.10.2020 by Leonov Vladislav 181-311

Конфигурация платы:
A0 - энкодер левого переднего колеса
A1 - энкодер правого переднего колеса
A2 - энкодер левого заднего колеса
A3 - энкодер правого заднего колеса
D8 - кнопка принудительного сброса  (кнопки DVRobot инвертированы, нажато == 0)

Опрос: без задержки // или с заержкой 10 ms 

Вывод значения в Serial - 0,5 сек - в формате counter\n

Управление по Serial
c - сброс (очистка)
p - не отправлять данные (пауза отправки, но не счёта импульсов!!!)
r - отправлять данные

(Устарело) ВНИМАНИЕ!  При старте передача данных остановлена (на паузе), чтобы не "шуметь" в СОМ-порт
(Теперь) После старта появляется сообщение #Ready, а затем делается сброс и начинается счёт и вывод данных

 ВНИМАНИЕ!  Переполнение счётчиков энкодеров не проверяется. 
 Это примерно 1500 оборотов колеса. То есть более километра по прямой. 
 Такое событие может наступить через 5-6 минут непрерывной езды без сброса на скорости 10 км/ч

*/

int sensorEncoderLeftPin = A1;    //  - энкодер левого колеса
int sensorEncoderRightPin = A0;   // - энкодер правого колеса

int EncoderLeftThreshold = 350;   // пороговое значение (низкий / высокий уровень)
int EncoderRightThreshold = 350;

int ledPin = 13;      // select the pin for the LED
int buttonPin = 8;

// счёт времени
unsigned long LastSendingMoment = 0; // время предыдущей отправки
unsigned long CurrentMoment = 0;

// частота (интервал) оправки данных
unsigned long SendingInterval = 500; // 500 ms

unsigned long LeftWheelCounter = 0;       // счётчик энкодера левого колеса
unsigned long RightWheelCounter = 0;      // счётчик энкодера правого колеса

// принцип мигания: - если значение меньше 
int sensorValue_EncoderLeft = 0;    // значение сенсора / максимум 1024
int sensorValue_EncoderRight = 0;     //
int sensorValue_Mix = 0;  // значение произвольного сенсора (при мониторинге работы пинов) 

int LastLeftEncoderLevel = 0;        // уровни (1/0) считанного значения с пина
int LastRightEncoderLevel = 0;
int CurrentLeftEncoderLevel = 0;
int CurrentRightEncoderLevel = 0;

// переменная для считывания команды через серийный порт
char cmd;

// переменная для контроля режима отправки данных
byte SendMode = 0;  // данные отправлять, 0 - не отправлять, 1 - отправлять данные
byte DataMode = 0;  // отправлять сумму, 1-левый энкодер, 2-правый энкодер, 3-аналоговые данные

//#-------- UDP configuration-------#
#include <Ethernet.h>
#include <EthernetUdp.h>
#include <SPI.h>
// Ниже укажите MAC-адрес и IP-адрес вашего контроллера .
// IP-адрес будет зависеть от настроек вашей локальной сети:
// При присваивании IP адрессов следует посмотреть доступные в маршрутизаторе
byte mac[] = {   0x90, 0xA2, 0xDA, 0x10, 0x13, 0xBB };
IPAddress boardIP (192, 168, 0, 202);                       // IP платы
IPAddress hostIP (192, 168, 0, 100);                        // IP server
unsigned int boardPort = 8092;                                // Порт платы
unsigned int hostPort = 9092;                                 // Порт сервера

EthernetUDP UDP;                                            // Создание экземпляра класса EthernetUDP для отправки и получения UDP-пакетов
char packetBuffer[UDP_TX_PACKET_MAX_SIZE];                  // Храним полученный пакет (приемный буфер Udp-пакета)
bool isStarted = false;                                     // Флаг работы программы
String com = "";
void setup() {  // стартовая процедура
  // declare the ledPin as an OUTPUT:
  pinMode(ledPin, OUTPUT);  
  pinMode(buttonPin, INPUT);
    
  delay(1000);
  
  Ethernet.begin(mac, boardIP);                           // Инициализируем плату контроллера
    UDP.begin(boardPort);                                   // Включаем прослушивание порта
    UDP.beginPacket(hostIP, hostPort);                     
    UDP.write("#CVL Wheel Encoders Board Ready!");  
    UDP.endPacket();
    
  // сбрасываем счётчики
  LeftWheelCounter = 0;       
  RightWheelCounter = 0;       
}

void loop() {  // бесконечный цикл

  // кнопка сброса счётчиков

//#1 Начало работы кода при включении платы один раз 
  if(UDP.parsePacket() > 0 && !isStarted){
    UDP.read(packetBuffer, UDP_TX_PACKET_MAX_SIZE);         // Cчитываем принятый пакет в буфер packetBufffer
    String comand = packetBuffer;                       
    comand.toLowerCase();
    if(comand == "start"){
      // Отсылаем пакет данных серверу:  
      UDP.beginPacket(hostIP, hostPort);                     
      UDP.write("#CVL Wheel Encoders Board Online");  
      UDP.endPacket();
      LastSendingMoment = millis();                         // Фиксируем момент последней отправки данных
      SendMode = 1;
      isStarted = true;
    }
  }
  //#1 Конец работы кода при включении платы один раз 
  if (isStarted){
    // обработка ввода-вывода по Ethernet  
    UDP.read(packetBuffer, UDP_TX_PACKET_MAX_SIZE);         // считываем принятый пакет в буфер packetBufffer

    //#2 Начало завершения работы кода 
    String comand = packetBuffer;                       
    comand.toLowerCase();
    if(comand == "end"){
    comand = "";
    // Отсылаем пакет данных серверу:  
    UDP.beginPacket(hostIP, hostPort);                        
    UDP.write("#CVL Wheel Encoders Board Offline");  
    UDP.endPacket();
    SendMode = 0;
    isStarted = false;
    }
    //#2 Конец завершения работы кода  
  
    char cmd = packetBuffer[0];                             // Считываем с принятого буфера первый символ
    switch(cmd){
      case 'C': case 'c': {  // сбрасываем счётчики
        LeftWheelCounter = 0;       
        RightWheelCounter = 0;       
      }; break;
      case 'P': case 'p': {  // ставим отправку на паузу
        SendMode = 0;
      }; break;
      case 'R': case 'r': {  // запускаем отправку
        SendMode = 1;
      }; break;
      case '0': {  // выводить сумму счётчиков
        DataMode = 0;
      }; break;
      case '1': {  // выводить удвоенный левый счётчик
        DataMode = 1;
      }; break;
      case '2': {  // выводить удвоенный правый счётчик
        DataMode = 2;
      }; break;      
      case 'A': case 'a': {  // выводить значения аналоговых портов
        DataMode = 3;
      }; break;
    }  
  }
  // считать сенсоры
  sensorValue_EncoderRight = analogRead(sensorEncoderLeftPin);    
  sensorValue_EncoderLeft = analogRead(sensorEncoderRightPin);

  // обработка энкодеров: аналог в уровень
  if (sensorValue_EncoderLeft > EncoderLeftThreshold) 
  {
     CurrentLeftEncoderLevel = 1;
  } else {
     CurrentLeftEncoderLevel = 0;
  }
  if (sensorValue_EncoderRight > EncoderRightThreshold) 
  {
     CurrentRightEncoderLevel = 1;
  } else {
     CurrentRightEncoderLevel = 0;
  }

  // обработка энкодеров: сравнение старый - новый уровень
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

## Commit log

2021-12-15 docs: add topology of project
    [Топология проекта KIA ProCeed.xlsx]
2021-12-15 init: control board of KIA ProCeed
